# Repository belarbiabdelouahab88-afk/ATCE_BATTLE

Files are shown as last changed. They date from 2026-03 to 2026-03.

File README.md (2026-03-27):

# ATCE_BATTLE
L3 SPI EA projet ATCE avec jmf

un groupe de 5 étudiants en licence EEA à l'université UMLP travaillent sur le projet d'ATCE, le but est de concevoir une carte comprenant un microcontrôleur Atmega32U4 chargé d’asservir la fréquence du quartz qui le cadence sur un signal stable fourni par un récepteur GPS.
Ce depot contient tous les fichiers de la partie programmation du microcontroleur.

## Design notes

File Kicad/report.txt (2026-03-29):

Info: Processing symbol 'C1:Capacitor_SMD:C_0805_2012Metric'.
Info: Processing symbol 'C2:Capacitor_SMD:C_0805_2012Metric'.
Info: Processing symbol 'C3:Capacitor_SMD:C_0805_2012Metric'.
Info: Processing symbol 'C4:Capacitor_SMD:C_0805_2012Metric'.
Info: Processing symbol 'C5:Capacitor_SMD:C_0805_2012Metric'.
Info: Processing symbol 'C6:Capacitor_SMD:C_0805_2012Metric'.
Info: Processing symbol 'C7:Capacitor_SMD:C_0805_2012Metric'.
Info: Processing symbol 'C8:Capacitor_SMD:C_0805_2012Metric'.
Info: Processing symbol 'C9:Capacitor_SMD:C_0805_2012Metric'.
Info: Processing symbol 'C10:Capacitor_SMD:C_0805_2012Metric'.
Info: Processing symbol 'C11:Capacitor_SMD:C_0805_2012Metric'.
Info: Processing symbol 'D1:Capacitor_SMD:C_0805_2012Metric'.
Info: Processing symbol 'D2:LED_SMD:LED_0805_2012Metric'.
Info: Processing symbol 'D3:LED_SMD:LED_0805_2012Metric'.
Info: Processing symbol 'D4:LED_SMD:LED_0805_2012Metric'.
Info: Processing symbol 'D5:LED_SMD:LED_0805_2012Metric'.
Info: Processing symbol 'H1:MountingHole:MountingHole_2.5mm'.
Info: Processing symbol 'H2:MountingHole:MountingHole_2.5mm'.
Info: Processing symbol 'H3:MountingHole:MountingHole_2.5mm'.
Info: Processing symbol 'H4:MountingHole:MountingHole_2.5mm'.
Info: Processing symbol 'J1:Connector_USB:USB_Mini-B_Lumberg_2486_01_Horizontal'.
Info: Processing symbol 'J2:Connector_Coaxial:SMA_Amphenol_901-143_Horizontal'.
Info: Processing symbol 'J3:Connector_PinHeader_1.00mm:PinHeader_1x02_P1.00mm_Horizontal'.
Info: Processing symbol 'L1:Inductor_SMD:L_0805_2012Metric'.
Info: Processing symbol 'R1:Resistor_SMD:R_0805_2012Metric'.
Info: Processing symbol 'R2:Resistor_SMD:R_0805_2012Metric'.
Info: Processing symbol 'R3:Resistor_SMD:R_0805_2012Metric'.
Info: Processing symbol 'R4:Resistor_SMD:R_0805_2012Metric'.
Info: Processing symbol 'R5:Resistor_SMD:R_0805_2012Metric'.
Info: Processing symbol 'SW1:Button_Switch_SMD:SW_Push_1P1T_NO_CK_KMR2'.
Info: Processing symbol 'SW3:Button_Switch_SMD:SW_Push_1P1T_NO_CK_KMR2'.
Info: Processing symbol 'TP1:TestPoint:TestPoint_Pad_1.0x1.0mm'.
Info: Processing symbol 'TP2:TestPoint:TestPoint_Pad_1.0x1.0mm'.
Info: Processing symbol 'TP3:TestPoint:TestPoint_Pad_1.0x1.0mm'.
Info: Total warnings: 0, errors: 0.
Info: Processing symbol 'U1:Package_QFP:TQFP-44_10x10mm_P0.8mm'.
Info: Processing symbol 'U2:Package_TO_SOT_SMD:TSOT-23-5'.
Info: Processing symbol 'Y1:Crystal:Crystal_SMD_HC49-SD_HandSoldering'.
Updated TP2 sheetname to '/'.
Updated TP2 sheetfile to 'ATCE.kicad_sch'.
Updated TP2 footprint filters to 'Pin* Test*'.
Removed TP2 'exclude from BOM' fabrication attribute.
Connected TP2 pin 1 to Net-(U2-+).
Added TP2 (footprint 'TestPoint:TestPoint_Pad_1.0x1.0mm').
Added TP3 (footprint 'TestPoint:TestPoint_Pad_1.0x1.0mm').
Changed REF** reference designator to TP2.
Changed TP3 value from TestPoint_Pad_1.0x1.0mm to TestPoint.
Updated TP3 symbol association from  to /187c50e6-ea0b-4c8a-bf67-23631c91052d.
Updated TP3 fields.
Updated TP3 sheetname to '/'.
Updated TP3 sheetfile to 'ATCE.kicad_sch'.
Updated TP3 footprint filters to 'Pin* Test*'.
Changed REF** reference designator to TP3.
Connected TP3 pin 1 to Net-(U1-PB5).
Changed TP2 value from TestPoint_Pad_1.0x1.0mm to TestPoint.
Updated TP2 symbol association from  to /06f01220-51ea-4944-8e5a-f59ea8672d4d.
Updated TP2 fields.

Removed TP3 'exclude from BOM' fabrication attribute.

Info: Total warnings: 0, errors: 0.

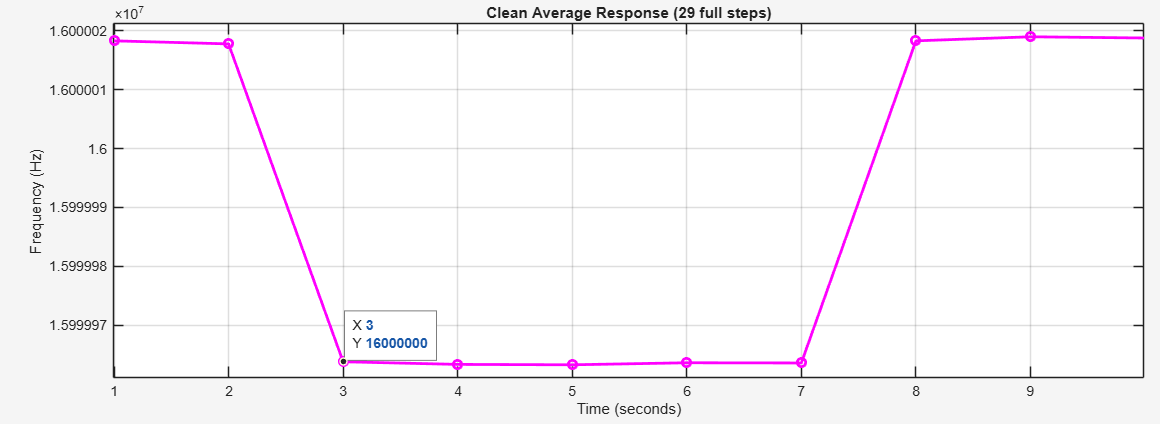
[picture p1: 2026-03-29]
Reponse_indicielle/Graphe/lareponseindiciellemoyenne.PNG

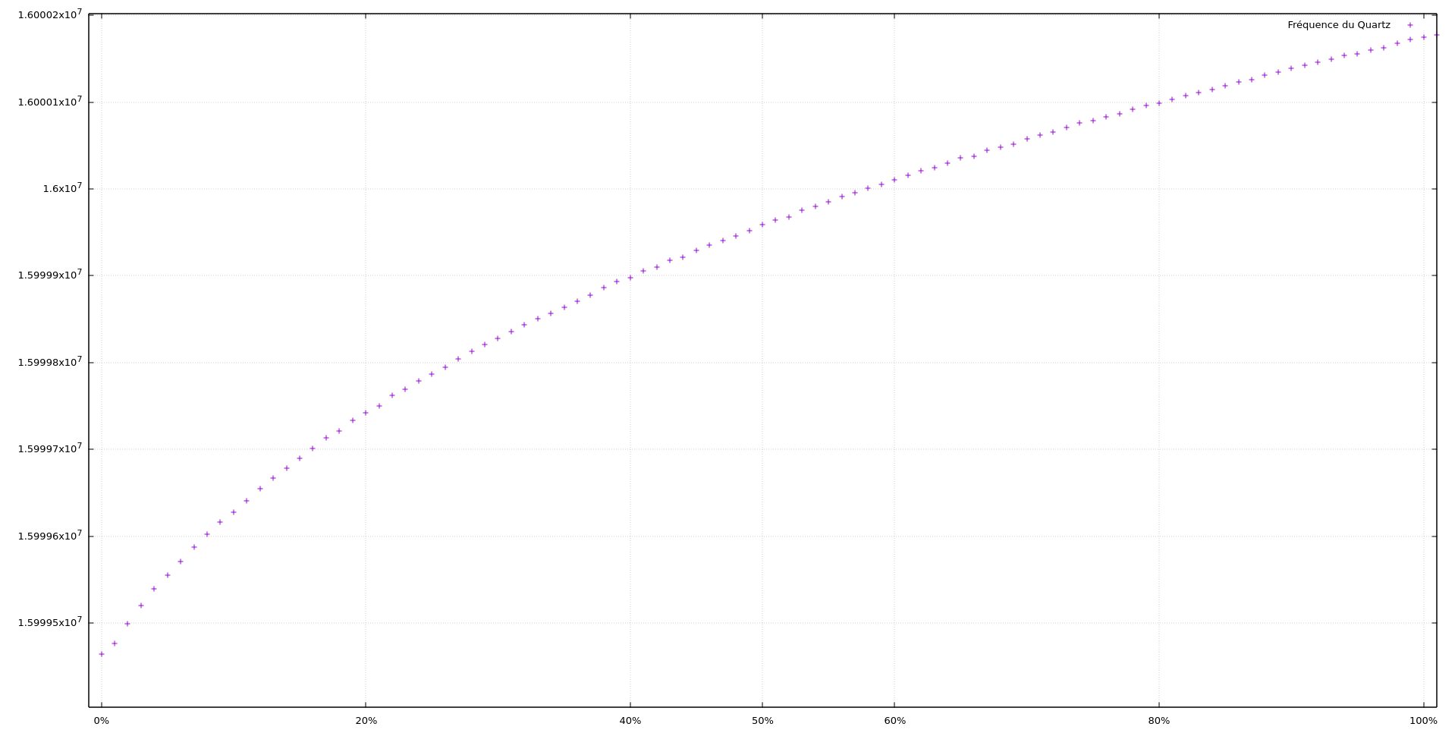
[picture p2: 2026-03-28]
Point de fonctionnement/Graphe/Point_de_fonctionnement.png

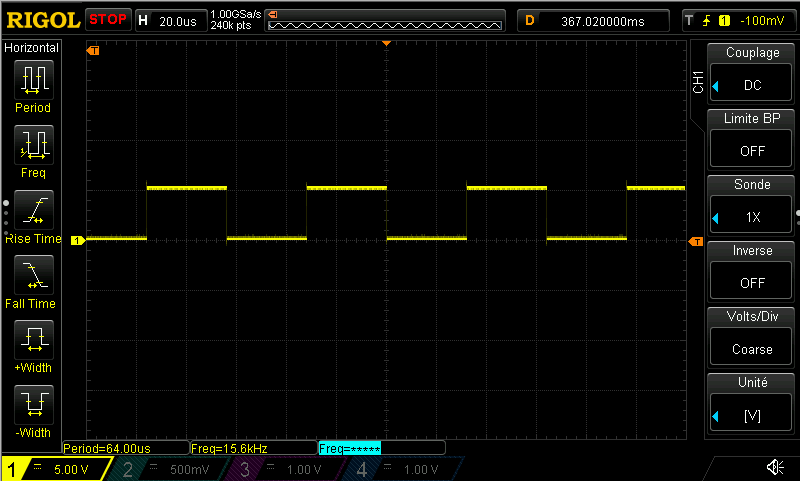
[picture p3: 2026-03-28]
pmw/Graphe/PWM_fast_mode.PNG

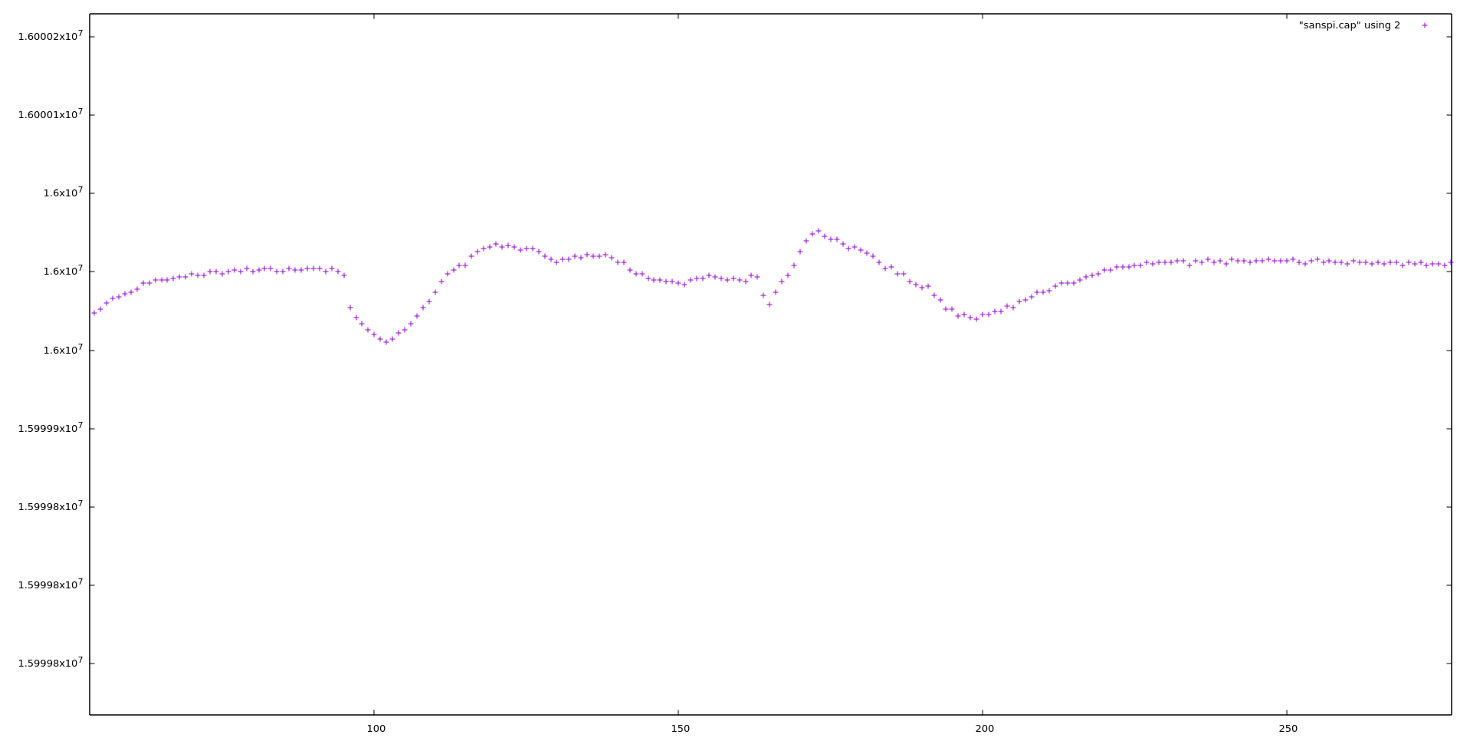
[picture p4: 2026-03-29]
PI regulation/Graphe/frequencePI.png

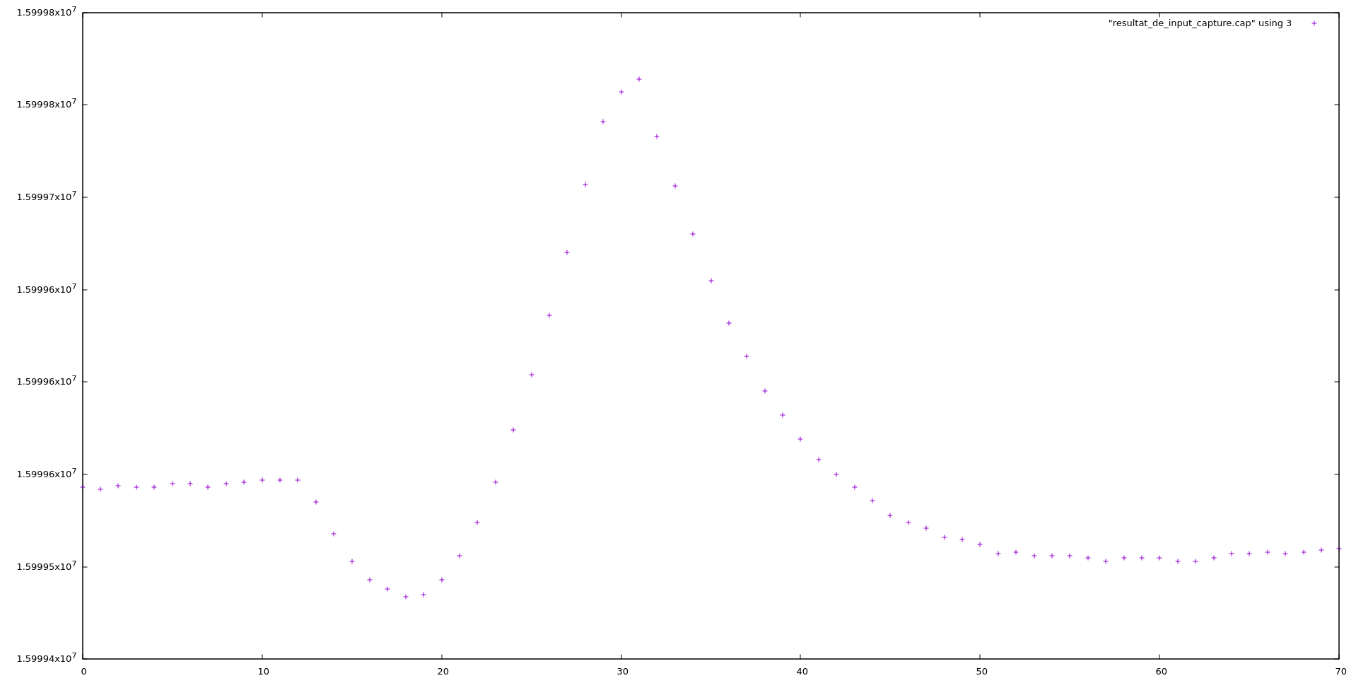
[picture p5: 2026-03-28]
INPUT capture/Graphe/mesure_inputCap.png

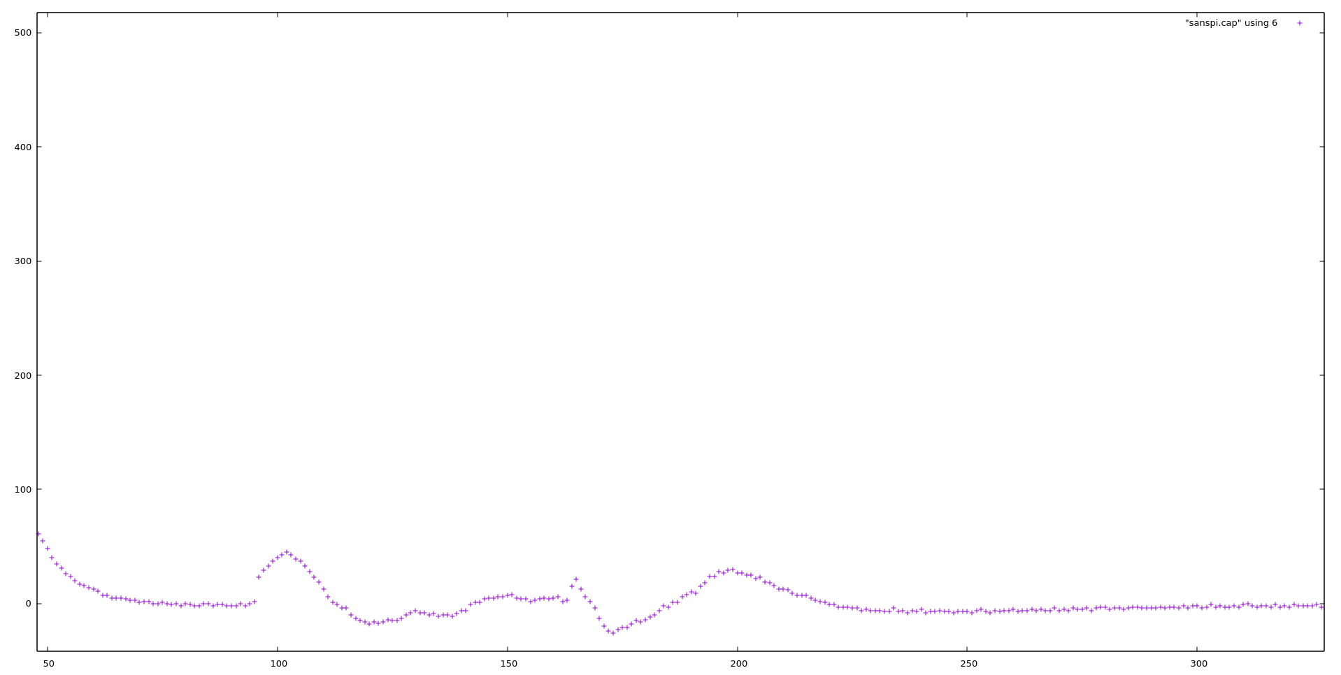
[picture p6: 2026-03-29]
PI regulation/Graphe/commandePI.png

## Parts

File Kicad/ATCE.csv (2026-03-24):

Reference | Qty | Value | DNP | Exclude from BOM | Exclude from Board | Footprint | Datasheet
C1,C2 | 2 | 20p |  |  |  | Capacitor_SMD:C_0805_2012Metric | ~
C3 | 1 | 5n |  |  |  | Capacitor_SMD:C_0805_2012Metric | ~
C4,C11,D1 | 3 | 1u |  |  |  | Capacitor_SMD:C_0805_2012Metric | ~
C5 | 1 | 10u |  |  |  | Capacitor_SMD:C_0805_2012Metric | ~
C6,C7,C8,C9,C10 | 5 | 100n |  |  |  | Capacitor_SMD:C_0805_2012Metric | ~
H1,H2,H3,H4 | 4 | MountingHole |  | Excluded from BOM |  | MountingHole:MountingHole_2.5mm | ~
J1 | 1 | USB_B_Mini |  |  |  | Connector_USB:USB_Mini-B_Lumberg_2486_01_Horizontal | ~
J2 | 1 | Conn_Coaxial |  |  |  | Connector_Coaxial:SMA_Amphenol_901-143_Horizontal | ~
L1 | 1 | 10u |  |  |  | Inductor_SMD:L_0805_2012Metric | ~
R1 | 1 | 10k |  |  |  | Resistor_SMD:R_0805_2012Metric | ~
R2 | 1 | 5600 |  |  |  | Resistor_SMD:R_0805_2012Metric | ~
R3 | 1 | 5.6k |  |  |  | Resistor_SMD:R_0805_2012Metric | ~
R4,R5 | 2 | 22 |  |  |  | Resistor_SMD:R_0805_2012Metric | ~
SW1,SW3 | 2 | SW_Push |  |  |  | Button_Switch_SMD:SW_Push_1P1T_NO_CK_KMR2 | ~
TP1,TP2,TP3 | 3 | TestPoint |  |  |  | TestPoint:TestPoint_Pad_1.0x1.0mm | ~
U1 | 1 | ATmega32U4-A |  |  |  | Package_QFP:TQFP-44_10x10mm_P0.8mm | http://ww1.microchip.com/downloads/en/DeviceDoc/Atmel-7766-8-bit-AVR-ATmega16U4-32U4_Datasheet.pdf
U2 | 1 | AD8603 |  |  |  | Package_TO_SOT_SMD:TSOT-23-5 | https://www.analog.com/media/en/technical-documentation/data-sheets/AD8603_8607_8609.pdf
Y1 | 1 | 16M |  |  |  | Crystal:Crystal_SMD_HC49-SD_HandSoldering | ~

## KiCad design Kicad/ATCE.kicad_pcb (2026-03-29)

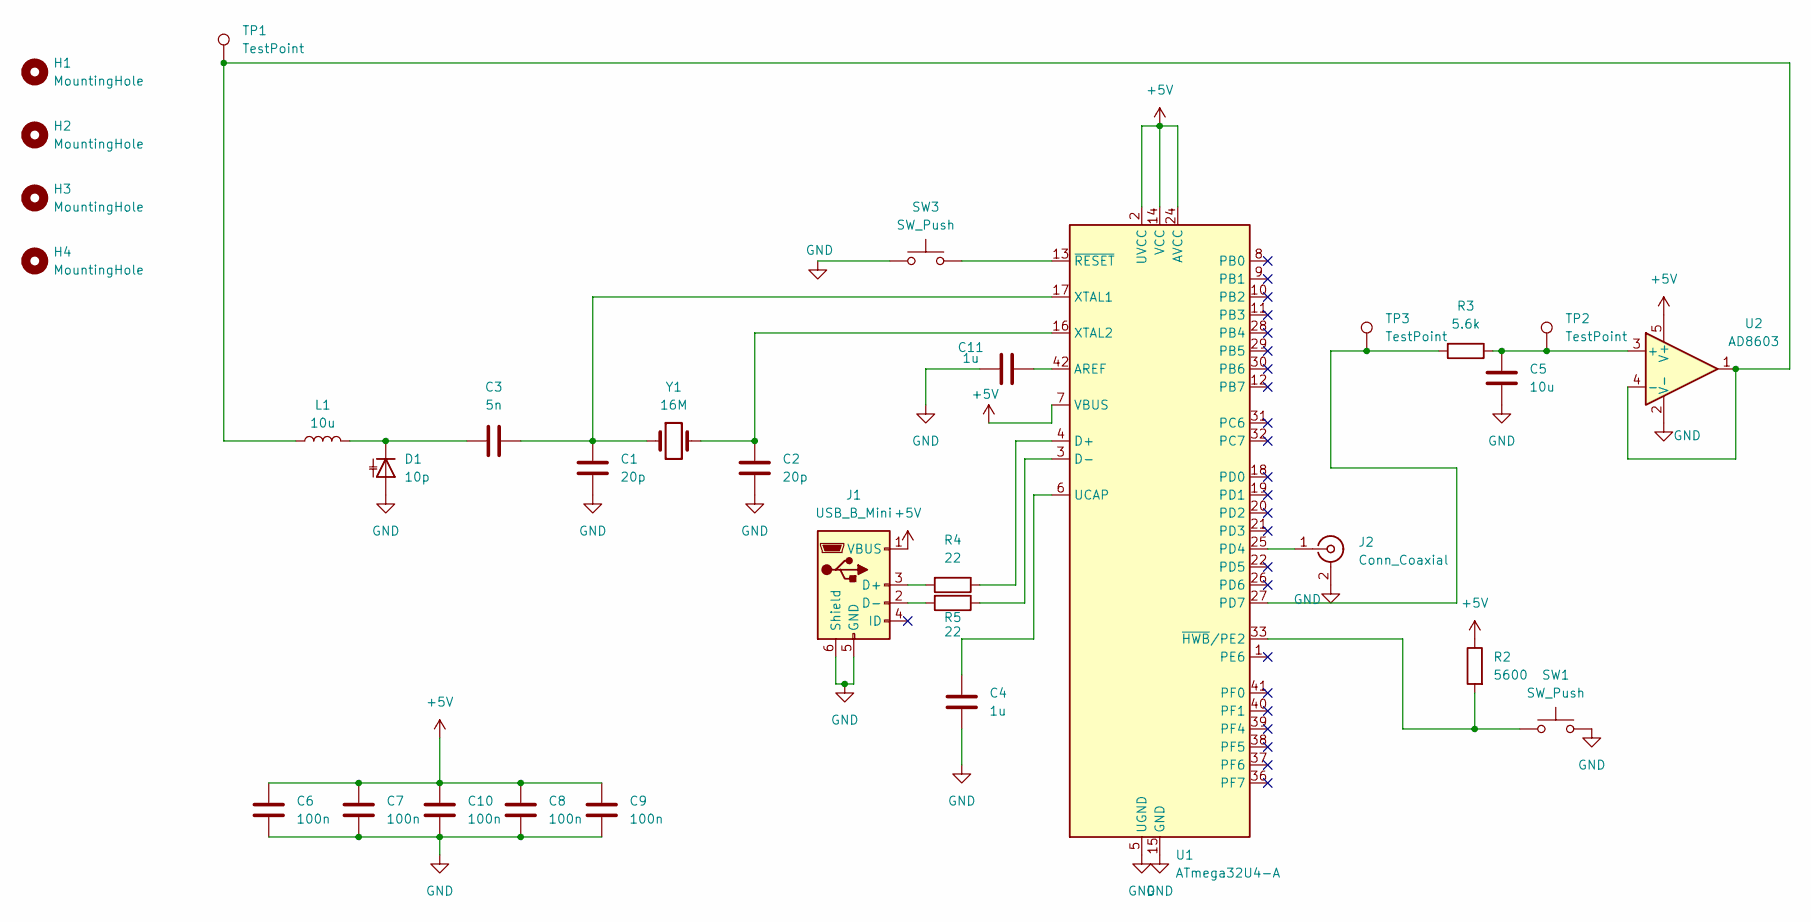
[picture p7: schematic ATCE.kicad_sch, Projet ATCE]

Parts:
C1, C2: 20p; C_0805_2012Metric
C3: 5n; C_0805_2012Metric
C4, C11: 1u; C_0805_2012Metric
C5: 10u; C_0805_2012Metric
C6, C7, C8, C9, C10: 100n; C_0805_2012Metric
D1: 10p; D_0805_2012Metric
H1, H2, H3, H4: MountingHole; MountingHole_2.5mm
J1: USB_B_Mini; USB_Mini-B_Lumberg_2486_01_Horizontal
J2: Conn_Coaxial; SMA_Amphenol_901-143_Horizontal
L1: 10u; L_0805_2012Metric
R2: 5600; R_0805_2012Metric
R3: 5.6k; R_0805_2012Metric
R4, R5: 22; R_0805_2012Metric
SW1, SW3: SW_Push; SW_Push_1P1T_NO_CK_KMR2
TP1, TP2, TP3: TestPoint; TestPoint_Pad_1.0x1.0mm
U1: ATmega32U4-A; TQFP-44_10x10mm_P0.8mm
U2: AD8603; TSOT-23-5
Y1: 16M; Crystal_SMD_HC49-SD_HandSoldering

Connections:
+5V: C6.1, C7.1, C8.1, C9.1, C10.1, J1.1 (VBUS), R2.1, U1.2 (UVCC), U1.7 (VBUS), U1.14 (VCC), U1.24 (AVCC), U1.34 (VCC), U1.44 (AVCC), U2.5 (V+)
GND: C1.2, C2.2, C4.2, C5.2, C6.2, C7.2, C8.2, C9.2, C10.2, C11.1, D1.2 (A), J1.5 (GND), J1.6 (Shield), J2.2 (Ext), SW1.2, SW3.1, U1.5 (UGND), U1.15 (GND), U1.23 (GND), U1.35 (GND), U1.43 (GND), U2.2 (V-)
unnamed: C3.1, D1.1 (K), L1.2
unnamed: J1.3 (D+), R4.2
unnamed: J1.2 (D-), R5.2
unnamed: J2.1 (In), U1.25 (PD4)
unnamed: C11.2, U1.42 (AREF)
unnamed: R4.1, U1.4 (D+)
unnamed: R5.1, U1.3 (D-)
unnamed: R3.2, TP3.1, U1.27 (PD7)
unnamed: C4.1, U1.6 (UCAP)
unnamed: C1.1, C3.2, U1.17 (XTAL1), Y1.1
unnamed: C2.1, U1.16 (XTAL2), Y1.2
unnamed: R2.2, SW1.1, U1.33 (~HWB/PE2)
unnamed: SW3.2, U1.13 (~RESET)
unnamed: C5.1, R3.1, TP2.1, U2.3 (+)
unnamed: L1.1, TP1.1, U2.1, U2.4 (-)

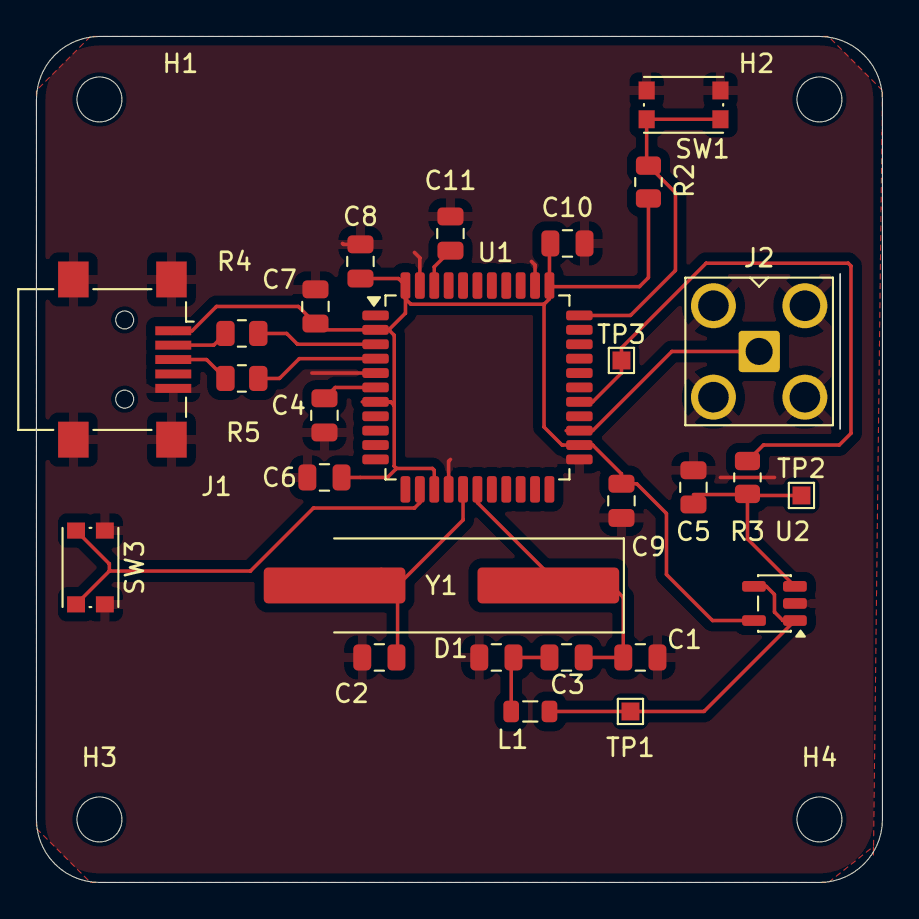
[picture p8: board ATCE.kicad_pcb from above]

Board: 2 copper layers, 47.0 x 47.0 mm, 31 parts (0 on the bottom side), 17 nets.

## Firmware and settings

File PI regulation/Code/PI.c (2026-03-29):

#define F_CPU 16000000UL      
#define F_USB 16000000UL  
#include <avr/io.h> 
#include <avr/interrupt.h> 
#include "VirtualSerial.h" 
#include <util/delay.h> 
 
#define kp  12 
#define ki  23 
#define consigne 15999958UL //Consigne qu'on a trouver aprés le calcule du point de fonctionnement de notre oscillateur
 
extern USB_ClassInfo_CDC_Device_t VirtualSerial_CDC_Interface; 
extern FILE USBSerialStream; 
 
volatile signed int pps2 = 0;         // valeur actuelle du timer (ICR1) 
volatile signed int overflow = 0;     // nombre d'overflow entre deux PPS 
volatile int nOVF = 0;                // copie pour calcul 
volatile signed long f = 0;           // fréquence calculée (nombre de ticks) 
volatile signed int delta = 0;        // différence entre deux captures 
volatile signed char flag = 0;        // indique qu'une nouvelle mesure est prête 
      
 
 
 
//----interrupts---- 
 
ISR (TIMER1_OVF_vect) { 
    overflow++; 
} 
 
ISR (TIMER1_CAPT_vect) { 
 
    pps2 = ICR1; 
    nOVF = overflow; 
    f = (((signed long)nOVF)*65536)+pps2; //Calcule de la frequance en decimale
     
    TCNT1 =0; 
    overflow = 0; 
    flag = 1; 
} 
//----functions---- 
 
void init_PWM () { 
     
    // PD7 = sortie OCR4D 
    DDRD |= (1 << PD7); 
     
    TCCR4D = (1 << PWM4X); 
 
    TCCR4C = (1 << COM4D1) | (1 << PWM4D); 
    TCCR4C &= ~(1 << COM4D0); 
 
    // TOP = 1023 (10 bits) 
    TC4H =  0x03; // Masque sur les 2 bits de poids fort 
    OCR4C =  0xFF; 
 
    // Rapport cyclique = 50% → 512 
    TC4H = 0x01;  
    OCR4D =0xFF; 
 
    // Prescaler = 1 
    TCCR4B = (1 << CS40); 
} 
 
//Fonction pour varier le rapport cyclique dans la boucle fermée
void PWM_rapport_cyclique (short RC) { 
    TC4H = (((RC) & 0x300) >> 8); 
    OCR4D = (RC & 0xFF); 
} 
 
 
void input_capture () { 
 
    DDRD &= ~(1 << PD4); //Entree de de notre 1PPS

 
    TCCR1B |= (1 << ICES1); 
    // sÃ©lection du front montant pour la capture 
 
    TIMSK1 |= (1 << ICIE1) | (1 << TOIE1); 
    // active : 
    // - interruption capture (ICIE1) 
    // - interruption overflow (TOIE1) 
 
    TCCR1B |= (1 << CS10); 
    // prescaler = 1 pour un autre registre
} 
 
 //saturation de la commande (anti-windup) pour eviter divergence 
int sature_commande(long commande) { 
    if (commande > 1023) return 1023; // Max positive ou negative
    if (commande < 0)    return 0;    // Min
    return (int)commande;  
} 
 
 
//-----main----- 
 
int main(void) { 
 
    SetupHardware(); 
    input_capture(); 
    init_PWM(); 
    CDC_Device_CreateStream(&VirtualSerial_CDC_Interface, &USBSerialStream); 
    GlobalInterruptEnable(); 
    sei(); //global interrupts too
 
   
    long erreur = 0; //erreur actuelle
    long erreur_old = 0; //erreur dans le PPS d'avant
    long commande_pwm = 0; //la valeur a appliquer au rapport cyclique pour corriger l'erreur
 
while (1) { 
	
    // Execution avec chaque PPS
    if (flag == 1) { 
         
        erreur = consigne - f; 

        commande_pwm = kp * (erreur - erreur_old) + ki * erreur; 
         
        // On accumule la commande pour modifier le point de fonctionnement 
        static long commande_accumulee = 0; 
        commande_accumulee += commande_pwm; 
 
        // Anti-windup
        if (commande_accumulee < -512000) commande_accumulee = -512000; 
        if (commande_accumulee > 511000)  commande_accumulee = 511000; 
 
        erreur_old = erreur; 
 
        // Mise à jour du PWM (Default 512 pour avoir une plage de variation positive our negative) 
        int rapport = 512 + (int)(commande_accumulee / 100); 
        PWM_rapport_cyclique(sature_commande(rapport)); 
 
        // Affichage des données 
        fprintf(&USBSerialStream, "F:%ld | Err:%ld | Cmd:%d\n\r", f, erreur, (int)(commande_accumulee / 100)); 
 
        // On baisse le flag pour attendre le prochain PPS 
        flag = 0; 
    } 
 
    CDC_Device_ReceiveByte(&VirtualSerial_CDC_Interface); 
    CDC_Device_USBTask(&VirtualSerial_CDC_Interface); 
    USB_USBTask(); 
    } 
} 

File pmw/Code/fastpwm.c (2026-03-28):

//Generation de la PWM du timer4 d'une resolution de 10 bits sur la sortie PD7 de l'atemega32u4
#define F_CPU 16000000UL
#define F_USB 16000000UL
#include <avr/io.h>
#include "VirtualSerial.h"
#include <util/delay.h>

extern USB_ClassInfo_CDC_Device_t VirtualSerial_CDC_Interface;
extern FILE USBSerialStream;

void init_PWM () {
	
    // PD7 = sortie OC4D
    DDRD |= (1 << PD7);
    
    // Activation du mode PWM_Fast
	TCCR4D = (1 << PWM4X); 

	//Activation de la PWM
    TCCR4C = (1 << COM4D1) | (1 << PWM4D);
    TCCR4C &= ~(1 << COM4D0);

    // Resolution de 1023
    TC4H =  0x03;  // Masque sur les 2 bits de poids fort
	OCR4C =  0xFF;

    // Rapport cyclique
    TC4H = 0x01; 
	OCR4D =0xFF;

    // Prescaler = 1
    TCCR4B = (1 << CS40);
}

int main(void) {
    init_PWM();
    SetupHardware();
    CDC_Device_CreateStream(&VirtualSerial_CDC_Interface, &USBSerialStream);
	GlobalInterruptEnable();
    while (1) {	
		
        }
}

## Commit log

2026-02-09 Add files via upload
    1st draft for main schematic
    [ATCE.kicad_pcb, ATCE.kicad_sch]
2026-03-24 Add files via upload
    BOM bill of materials
    [${ATCE}.csv]
2026-03-24 Add files via upload
    Partie LED
2026-03-24 Create led.c
    L'allumage des LED et la désactivition du JTAG
2026-03-26 Create pwm
2026-03-27 Create pid.c
    Regulation pid (ilya encore des trucs a supprimer)
2026-03-28 Update fastpwm.c
    Generation d'une PWM_fast_mode sur le portD7 de l'atmega32u4
2026-03-28 Create Reponse_indicielle.c
    Temps de reponse du systeme a atteindre la consigne
2026-03-28 Create point_de_fonct.c
    Variation du rapport cyclique de 0 a 100% sur les mesures de frequences
2026-03-28 Create InputCap.c
    Capture du signal 1PPS sur le compteur du Timer1
2026-03-28 Create mesure_input_capture.txt
    Mesure de l'input capture avec le comportement en frequence lorsque le quartz est soumis a une source chaude dans notre cas c'est le fer a soude
2026-03-28 Add files via upload
    Simulation d'un signal 1PPS avec comme caracteristique une amplitude de 3,3V et un rapport cyclique de 20%
2026-03-28 Add files via upload
    Signal de la PWM en mode Fast avec une frequence de 15Khz
2026-03-28 Add files via upload
    Signal de commande de la regulation PI
2026-03-28 Rename Point de fonctionnement/Point_de_fonctionnement.png to Point de fonctionnement/Graphe/Point_de_fonctionnement.png
2026-03-28 Rename Point de fonctionnement/point_de_fonct.c to Point de fonctionnement/Code/point_de_fonct.c
2026-03-28 Rename Point de fonctionnement/makefile to Point de fonctionnement/Code/makefile
